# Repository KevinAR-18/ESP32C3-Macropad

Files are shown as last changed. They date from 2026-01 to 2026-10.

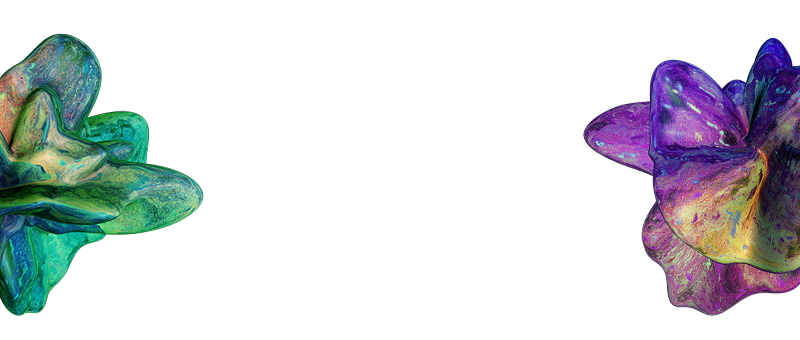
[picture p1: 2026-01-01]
images/bg3.png

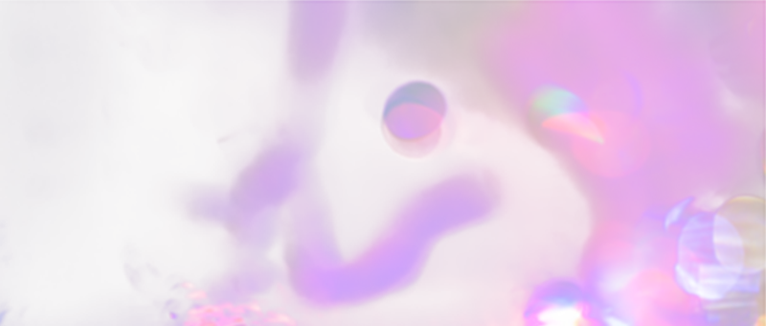
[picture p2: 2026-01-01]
images/bg.png

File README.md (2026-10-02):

# KeyBloom

KeyBloom is a Windows desktop companion for a custom ESP32-C3 macro pad. It provides a PySide6-based interface to configure multiple profiles, map each hardware button to a keyboard shortcut or application launcher, and keep the app running in the system tray while listening to serial events from the device.

## Features

- 5 configurable profiles
- 6 slots per profile
- Keyboard shortcut capture with presets
- Media key capture support, including fallback for `Fn`-based media keys
- Application launcher per slot
- ESP32 serial auto-detection with reconnect retry/backoff
- USB-priority transport with verified handshake and heartbeat
- BLE scan/connect/disconnect/forget inside KeyBloom, with saved-device reconnect
- BLE idle power reduction and encoder-1-only deep-sleep wake
- System tray mode for background runtime
- Windows startup integration with start-minimized tray behavior
- Default startup page always returns to Profile 1
- Settings stored in `%APPDATA%\KeyBloom\settings.json`
- Spotify session volume control for the second encoder
- KiCad PCB files included in the repository
- ESP32-C3 firmware source included in the repository

## Project Structure

- [main.py](./main.py): application entry point and main runtime logic
- [keybloom.ui](./keybloom.ui): Qt Designer source file
- [ui/ui_keybloom.py](./ui/ui_keybloom.py): generated Qt UI file
- [ui/preview_button.py](./ui/preview_button.py): custom keycap preview widget
- [ui/ui_functions.py](./ui/ui_functions.py): borderless window and drag helpers
- [config/settings_manager.py](./config/settings_manager.py): settings load/save and profile serialization
- [input/key_capture.py](./input/key_capture.py): shortcut capture event filter
- [input/shortcut_utils.py](./input/shortcut_utils.py): shortcut normalization helpers
- [serial_tools/port_detector.py](./serial_tools/port_detector.py): serial port auto-detection helpers
- [connection/manager.py](./connection/manager.py): background USB/BLE transport and connection policy
- [connection/dialog.py](./connection/dialog.py): connection and power settings dialog
- [utils/date_utils.py](./utils/date_utils.py): clock/date formatting helper
- [resources.qrc](./resources.qrc): Qt resource manifest
- [resources_rc.py](./resources_rc.py): generated Qt resource module
- [build.bat](./build.bat): main PyInstaller build script
- [KeyBloom.spec](./KeyBloom.spec): PyInstaller spec file
- [examplebuildbat.bat](./examplebuildbat.bat): simplified build example
- [PCB_Macropad/Macropad_PCB](./PCB_Macropad/Macropad_PCB): KiCad project for the macro pad PCB
- [ProgramESP32C3_Macropad/ProgramESP32C3_Macropad.ino](./ProgramESP32C3_Macropad/ProgramESP32C3_Macropad.ino): ESP32-C3 firmware source
- [bluetooth_test](./bluetooth_test): isolated ESP32-C3 BLE communication prototype for Windows 11

## Requirements

- Windows
- Python 3.12+ recommended
- A virtual environment in `.venv`
- ESP32-C3 macro pad firmware that sends serial messages compatible with the app

Install dependencies:

```powershell
.venv\Scripts\python.exe -m pip install -r requirements.txt
```

## Running From Source

```powershell
.venv\Scripts\python.exe main.py
```

## Runtime Behavior

- When Auto Startup is enabled, Windows launches KeyBloom with a start-minimized flag so the app goes directly to the system tray.
- When the main window is opened manually, the app always starts on Profile 1.
- Shortcut capture uses the Qt event path first and temporarily enables a global keyboard hook while recording, which improves capture for media keys such as `Media Next` and `Media Previous`.
- Serial auto-detect keeps retrying with a reconnect backoff when the ESP32-C3 disconnects or re-enumerates.

## Settings Location

At runtime, the app saves settings to:

```text
%APPDATA%\KeyBloom\settings.json
```

Legacy settings next to the executable or project folder are still readable as fallback.

## Build EXE

Install PyInstaller first:

```powershell
.venv\Scripts\python.exe -m pip install pyinstaller
```

Then run:

```powershell
build.bat
```

Expected output:

```text
dist\KeyBloom.exe
dist\icon.ico
```

`build.bat` also copies `icon.ico` into `dist\` after a successful build.

## Hardware Files

The repository also includes the hardware design files for the macro pad PCB.

- The KiCad project is located in [PCB_Macropad/Macropad_PCB](./PCB_Macropad/Macropad_PCB).
- The PCB design files are already prepared for production and intended for JLCPCB workflow.
- The project includes the schematic, PCB layout, and backup archives generated during board iteration.

## ESP32-C3 Firmware

### Dual USB/BLE setup

Upload `ProgramESP32C3_Macropad/ProgramESP32C3_Macropad.ino` with
**NimBLE-Arduino 2.x** installed. Compilation has been checked with Arduino-ESP32
**3.3.10**, target `esp32:esp32:esp32c3:CDCOnBoot=cdc` (native USB CDC enabled).
Choose the board/USB settings matching your actual hardware. Close Serial Monitor
before connecting KeyBloom. Update both desktop app and firmware together: the old
serial firmware and BLE test firmware do not implement the production handshake/control protocol.

Open **Settings → USB / Bluetooth Connection…**, or **Connection…** in the tray menu.

1. For USB, enable Auto Detect (or enter the COM port manually). KeyBloom verifies
   the device before selecting USB. An open COM port alone is not sufficient.
2. For BLE, click **Scan**, select `KeyBloom-C3`, then **Connect**. Use the KeyBloom
   dialog rather than Windows Bluetooth pairing. The device is saved only after
   the BLE service, control write, and event subscription succeed.
3. Saved devices reconnect on app startup and after an unexpected disconnection.
4. **Disconnect** keeps the device saved and disables reconnect, including after
   an app restart. **Connect** enables it again. **Forget device** removes the saved device.
5. USB takes priority. Removing USB permits BLE reconnect unless manually disconnected.
   A charging cable without an active KeyBloom data connection does not select USB.

The board needs battery/another power source to keep running when USB is removed.
The prototype BLE client must be closed before connecting the desktop app.

### Custom button and rotary actions

- On any profile page, click **Edit button & rotary actions…** or click a button
  preview and choose **Edit Action…**.
- Each profile has 12 mappings: six buttons and left/right/click for each rotary.
- Available actions: keyboard shortcut, media (play/pause, next, previous, stop),
  system audio, Spotify volume, open app/file/folder, URL, text, switch profile,
  and None. Spotify volume steps can be set from 1% to 100%.
- Text preserves whitespace and is typed into the focused application. Media
  controls use the Windows media session; they are not Spotify-specific.
- **Copy/Paste** copies one mapping. The profile selector copies all 12 mappings
  from another profile. **Export/Import profile** uses a portable JSON file.
  Imported/copied changes take effect only after **Save**; Cancel discards them.
- Mappings are saved in the application's settings and restored on restart.
  Existing button mappings and the original rotary defaults are retained.
- Firmware currently repeats held buttons; briefly press toggle actions such
  as Play/Pause and profile switching. Long/double press are not available yet.

### Power and wake-up behavior

- Default: after **60 seconds** of physical inactivity, request longer BLE connection
  intervals/slave latency and slower advertising when disconnected. The central
  (Windows) can negotiate different connection parameters.
- Stock Arduino-ESP32 3.3.10 in this environment has `CONFIG_PM_ENABLE` and
  `CONFIG_BT_CTRL_MODEM_SLEEP` disabled. This build reduces CPU speed to **80 MHz**
  while idle and restores **160 MHz** on activity/USB. It does **not** claim connected
  automatic light-sleep. Custom cores with compatible PM/modem-sleep/tickless-idle
  support can use the guarded PM configuration in the sketch.
- Default: after **600 seconds**, enter deep sleep and disconnect BLE. This also
  applies when advertising without a connected client. Active USB heartbeat prevents sleep.
- **Only clicking encoder 1 (GPIO 5) wakes from deep sleep.** Rotation and other
  buttons do not wake it. The complete wake click, including hold/repeat, is consumed;
  release it before using encoder 1 again.
- KeyBloom reconnects to a waking saved device unless Disconnect was selected.
  A sleeping board cannot be woken by the app's Connect button. Click encoder 1 first.
- USB plug-in wake depends on the board's power/reset wiring; do not assume it wakes
  an already battery-powered sleeping board. Use encoder 1 if needed.
- Change timings or disable deep sleep with **Save power settings**. Settings are saved
  in AppData and sent on connection; firmware persists changed power settings in NVS.
- Sleep status is shown when the firmware's notification reaches the app. A silent
  disconnect cannot reliably be identified as sleep. Reconnect scanning backs off to 30 seconds.

Hardware verification is still required: measure board current in active/idle/deep-sleep
states, confirm GPIO 5 remains pulled high when released, exercise wake/reconnect and
USB hot-plug, and check that LED/regulator consumption meets your battery-life needs.
Do not infer battery life from firmware sleep mode alone.

### Protocol and validation

BLE name/service/event UUID remain compatible with the prototype. Production adds
the writable control characteristic `7c3a0003-8f6e-4d4b-a8f3-6f8f9c1b0001`.

- USB: `KB HELLO <session>` → `KB READY <session>`.
- Heartbeat every second: `KB PING <session>` → `KB PONG <session>`; 3-second lease.
- Graceful release: `KB BYE <session>`.
- Power configuration: `KB POWER <0|1> <idle_seconds> <sleep_seconds>` over USB or BLE.
- Before deep sleep: BLE notification `KB SLEEP` (best effort).

Run desktop policy tests and the isolated UI smoke check:

```powershell
.venv\Scripts\python.exe -m unittest discover -s tests -v
.venv\Scripts\python.exe tests\smoke_ui.py
```

The ESP32-C3 firmware is already included in the repository:

- Firmware source: [ProgramESP32C3_Macropad/ProgramESP32C3_Macropad.ino](./ProgramESP32C3_Macropad/ProgramESP32C3_Macropad.ino)
- The desktop app expects the board firmware to send serial messages that match the event format documented below.

## Serial Event Format

The app currently reacts to messages such as:

```text
BUTTON 1 PRESSED
ENC1 RIGHT
ENC1 LEFT
ENC1 BUTTON PRESSED
ENC2 RIGHT
ENC2 LEFT
ENC2 BUTTON PRESSED
START
```

## Notes

- The UI is generated from `keybloom.ui`, but runtime optimizations are handled in Python code.
- The app is tuned to stay lighter while minimized to tray by reducing unnecessary timers, delayed widget setup, and lazy-loading heavy modules.
- `requirements.txt` is kept intentionally small to match the runtime dependencies used by the current app.

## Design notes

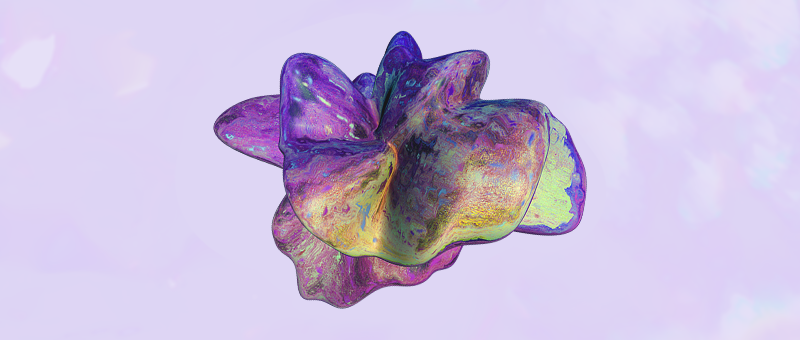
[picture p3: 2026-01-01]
images/bg2.png

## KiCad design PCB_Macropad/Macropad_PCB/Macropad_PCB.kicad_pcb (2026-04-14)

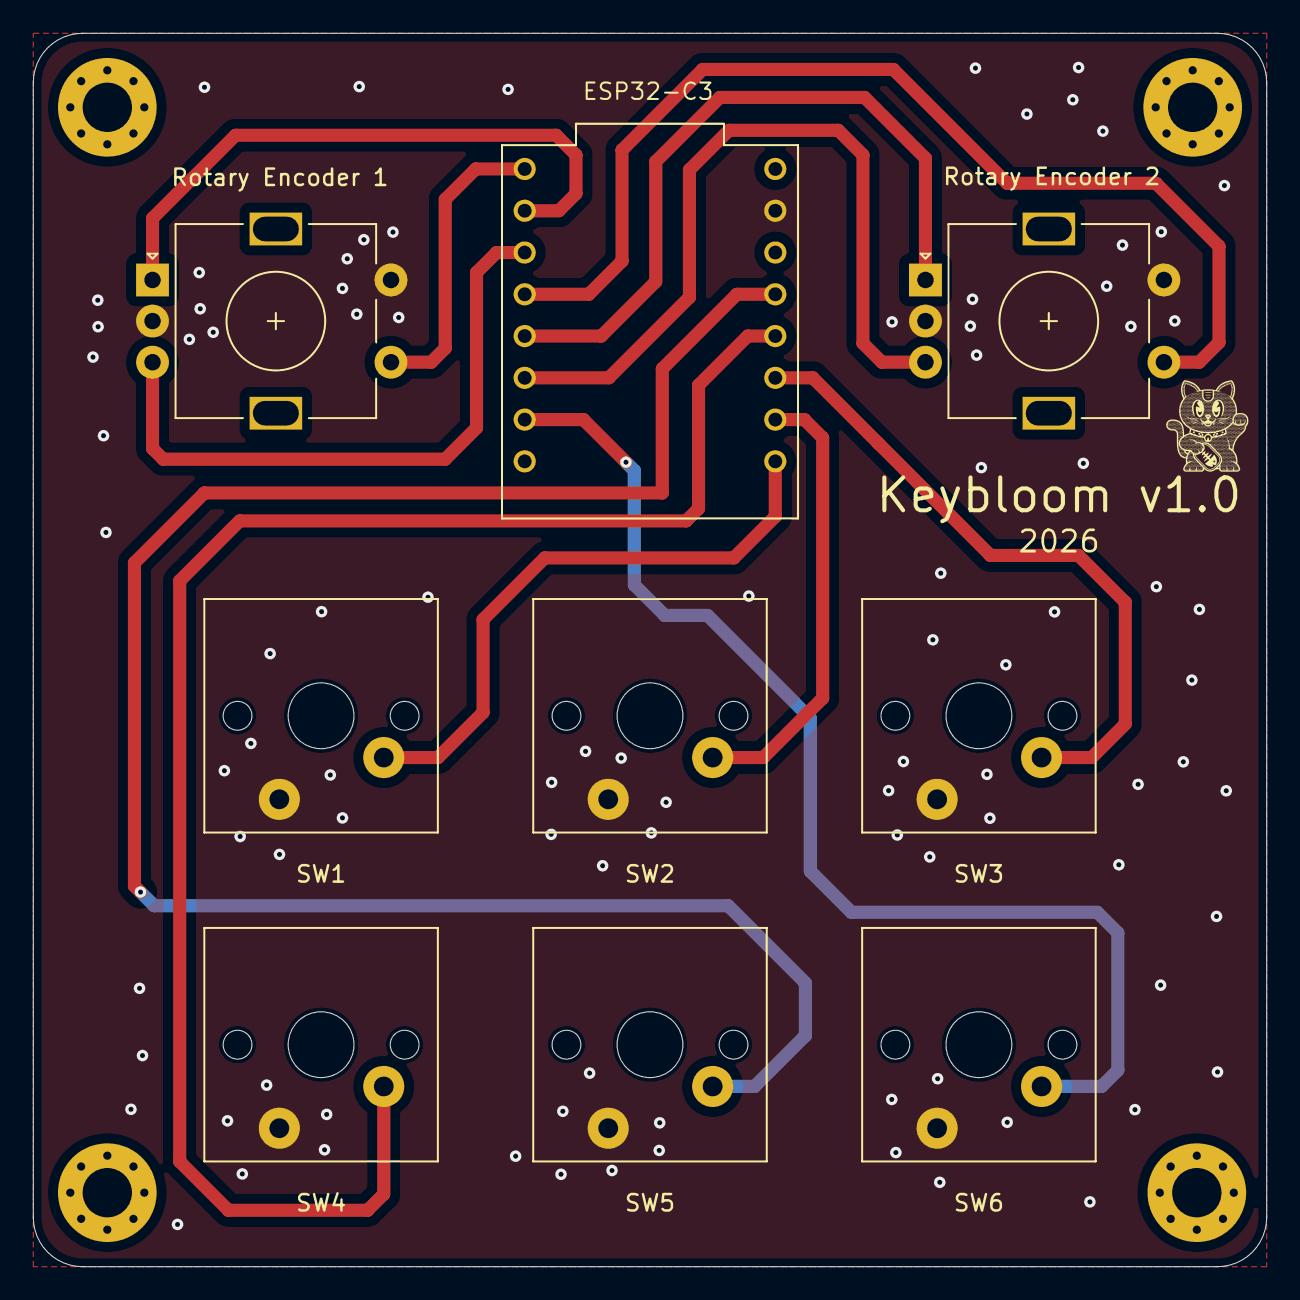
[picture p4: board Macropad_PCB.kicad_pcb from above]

Board: 2 copper layers, 75.0 x 75.0 mm, 13 parts (0 on the bottom side), 13 nets.

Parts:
ESP32-C3: ESP32-C3; MODULE_ESP32-C3_SUPERMINI_TH
H3, H4, H5, H6: MountingHole; MountingHole_3mm_Pad_Via
Rotary Encoder 1: Rotary Encoder Switch 1; RotaryEncoder_Alps_EC11E-Switch_Vertical_H20mm
Rotary Encoder 2: Rotary Encoder Switch 2; RotaryEncoder_Alps_EC11E-Switch_Vertical_H20mm
SW1: Button 1; SW_Cherry_MX_PCB_1.00u
SW2: Button 2; SW_Cherry_MX_PCB_1.00u
SW3: Button 3; SW_Cherry_MX_PCB_1.00u
SW4: Button 4; SW_Cherry_MX_PCB_1.00u
SW5: Button 5; SW_Cherry_MX_PCB_1.00u
SW6: Button 6; SW_Cherry_MX_PCB_1.00u

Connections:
D0: ESP32-C3.0 (GPIO0), SW1.1 (A)
D1: ESP32-C3.1 (GPIO1), SW2.1 (A)
D2: ESP32-C3.2 (GPIO2), SW3.1 (A)
D3: ESP32-C3.3 (GPIO3), SW4.1 (A)
D4: ESP32-C3.4 (GPIO4), SW5.1 (A)
D5: ESP32-C3.5 (GPIO5), Rotary Encoder 1.S1
D6: ESP32-C3.6 (GPIO6), Rotary Encoder 1.A
D7: ESP32-C3.7 (GPIO7), Rotary Encoder 1.B
D8: ESP32-C3.8 (GPIO8), Rotary Encoder 2.S1
D9: ESP32-C3.9 (GPIO9), Rotary Encoder 2.A
D10: ESP32-C3.10 (GPIO10), Rotary Encoder 2.B
D20: ESP32-C3.20 (GPIO20), SW6.1 (A)
GND: ESP32-C3.G (GND), Rotary Encoder 1.C, Rotary Encoder 1.S2, Rotary Encoder 2.C, Rotary Encoder 2.S2, SW1.2 (B), SW2.2 (B), SW3.2 (B), SW4.2 (B), SW5.2 (B), SW6.2 (B)

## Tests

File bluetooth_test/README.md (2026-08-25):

# KeyBloom ESP32-C3 BLE Prototype

Prototype ini menguji komunikasi BLE antara ESP32-C3 dan Windows 11 tanpa mengubah aplikasi atau firmware utama KeyBloom.

## Arsitektur

- Nama BLE: `KeyBloom-C3`
- Service UUID: `7c3a0001-8f6e-4d4b-a8f3-6f8f9c1b0001`
- Event characteristic UUID: `7c3a0002-8f6e-4d4b-a8f3-6f8f9c1b0001`
- Transport: custom BLE GATT notification
- Pairing tidak diperlukan untuk prototype ini

Format event sengaja sama dengan firmware serial utama:

```text
BUTTON 1 PRESSED
ENC1 RIGHT
ENC1 LEFT
ENC1 BUTTON PRESSED
ENC2 RIGHT
ENC2 LEFT
ENC2 BUTTON PRESSED
```

## 1. Siapkan Arduino IDE

1. Pastikan board package `esp32 by Espressif Systems` sudah terpasang.
2. Pilih board ESP32-C3 yang sesuai dengan hardware.
3. Buka `ESP32C3_BLE_Test/ESP32C3_BLE_Test.ino`.
4. Install library `NimBLE-Arduino` versi 2.x melalui Library Manager.
5. Upload firmware ke ESP32-C3.
6. Buka Serial Monitor dengan baud `115200`.

Output awal yang diharapkan:

```text
[BLE] Advertising as KeyBloom-C3
START
```

## 2. Siapkan Python

Dari root repository:

```powershell
python -m venv bluetooth_test\.venv
bluetooth_test\.venv\Scripts\python.exe -m pip install -r bluetooth_test\requirements.txt
```

## 3. Scan Perangkat

Pastikan Bluetooth Windows 11 aktif, lalu jalankan:

```powershell
bluetooth_test\.venv\Scripts\python.exe bluetooth_test\bluetooth_test.py --scan-only
```

Cari perangkat bernama `KeyBloom-C3` atau baris yang memiliki marker `<KeyBloom>`.

## 4. Connect dan Dengarkan Event

```powershell
bluetooth_test\.venv\Scripts\python.exe bluetooth_test\bluetooth_test.py
```

Tekan tombol dan putar encoder. Contoh output:

```text
[BLE] Connected: True
[14:20:30.804] [EVENT] START
[BLE] Listening for events. Press Ctrl+C to stop.
[14:20:31.125] [EVENT] BUTTON 1 PRESSED
[14:20:33.421] [EVENT] ENC1 RIGHT
```

Klien otomatis melakukan scan dan reconnect ketika ESP32 dimatikan atau koneksi terputus.

Jika pencarian berdasarkan nama gagal tetapi alamat terlihat saat scan, gunakan:

```powershell
bluetooth_test\.venv\Scripts\python.exe bluetooth_test\bluetooth_test.py --address "ALAMAT_DARI_HASIL_SCAN"
```

Pada Windows, address dari Bleak dapat berupa UUID dan bukan MAC address. Gunakan nilai persis seperti hasil scan.

## Checklist Pengujian

- ESP32 muncul sebagai `KeyBloom-C3`.
- Python dapat connect tanpa pairing manual.
- Semua enam tombol menghasilkan event yang benar.
- Kedua encoder menghasilkan arah dan event tombol yang benar.
- Tidak ada event ganda untuk satu detent encoder.
- Python mendeteksi disconnect ketika ESP32 dimatikan.
- Python reconnect setelah ESP32 dinyalakan kembali.
- Koneksi tetap stabil setidaknya 30 menit.

## Catatan

- ESP32-C3 mendukung BLE, bukan Bluetooth Classic SPP.
- Firmware ini tetap mencetak semua event ke serial untuk membantu debugging.
- Jangan mengganti firmware utama sebelum prototype ini lolos pengujian.

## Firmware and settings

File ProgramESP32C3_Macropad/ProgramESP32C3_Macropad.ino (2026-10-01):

#include <NimBLEDevice.h>
#include <Preferences.h>
#include <esp_sleep.h>
#include <esp_pm.h>
#include <driver/gpio.h>

// ESP32-C3 / NimBLE-Arduino 2.x. GPIO 5 is the ONLY deep-sleep wake button.
const uint8_t buttonPins[] = {0, 1, 2, 3, 4, 20, 5, 8};
const uint8_t encA[] = {6, 9};
const uint8_t encB[] = {7, 10};
const char *SERVICE_UUID = "7c3a0001-8f6e-4d4b-a8f3-6f8f9c1b0001";
const char *EVENT_UUID = "7c3a0002-8f6e-4d4b-a8f3-6f8f9c1b0001";
const char *CONTROL_UUID = "7c3a0003-8f6e-4d4b-a8f3-6f8f9c1b0001";
constexpr uint32_t DEBOUNCE_MS = 50, REPEAT_DELAY = 400, REPEAT_RATE = 80;
constexpr uint32_t USB_TIMEOUT = 3000;

struct Button {
  bool raw = HIGH, stable = HIGH;
  uint32_t changed = 0, pressed = 0, repeated = 0;
};
Button buttons[8];
int lastEncoderA[2];
bool suppressWakeClick = false;
uint32_t lastActivity = 0, lastHeartbeat = 0;
bool usbActive = false, idleMode = false, sleepEnabled = true;
uint32_t idleMs = 60000, sleepMs = 600000;
String serialLine, usbSession;
Preferences preferences;
NimBLEServer *bleServer = nullptr;
NimBLECharacteristic *events = nullptr;
volatile bool bleConnected = false;
volatile bool restartAdvertising = false, updateParams = false;
volatile uint16_t connectionHandle = BLE_HS_CONN_HANDLE_NONE;

// BLE callbacks run on another task. Transfer configuration through a bounded queue.
struct ControlMessage { char text[80]; };
QueueHandle_t controls;

class ServerCallbacks : public NimBLEServerCallbacks {
  void onConnect(NimBLEServer *, NimBLEConnInfo &info) override {
    connectionHandle = info.getConnHandle();
    bleConnected = true;
    updateParams = true;
  }
  void onDisconnect(NimBLEServer *, NimBLEConnInfo &, int) override {
    bleConnected = false;
    connectionHandle = BLE_HS_CONN_HANDLE_NONE;
    restartAdvertising = true;
  }
};

class ControlCallbacks : public NimBLECharacteristicCallbacks {
  void onWrite(NimBLECharacteristic *characteristic, NimBLEConnInfo &) override {
    auto value = characteristic->getValue();
    if (value.size() >= sizeof(ControlMessage::text)) return;
    ControlMessage message = {};
    memcpy(message.text, value.c_str(), value.size());
    xQueueSend(controls, &message, 0);
  }
};

void sendEvent(const String &text) {
  if (usbActive) {
    Serial.println(text);
  } else if (bleConnected) {
    events->setValue(text.c_str());
    events->notify();
  }
}

void setPowerConfig(const String &command) {
  unsigned int enabled, idleSeconds, sleepSeconds;
  char extra;
  if (sscanf(command.c_str(), "KB POWER %u %u %u %c", &enabled, &idleSeconds,
             &sleepSeconds, &extra) != 3) return;
  if (enabled > 1 || idleSeconds < 10 || idleSeconds > 3600 ||
      sleepSeconds <= idleSeconds || sleepSeconds > 86400) return;
  bool changed = sleepEnabled != bool(enabled) || idleMs != idleSeconds * 1000UL ||
                 sleepMs != sleepSeconds * 1000UL;
  sleepEnabled = enabled;
  idleMs = idleSeconds * 1000UL;
  sleepMs = sleepSeconds * 1000UL;
  if (changed) {
    preferences.putBool("enabled", sleepEnabled);
    preferences.putUInt("idle", idleMs);
    preferences.putUInt("sleep", sleepMs);
  }
}

void handleSerial() {
  // Limit work per pass so malformed traffic cannot starve physical input.
  for (int i = 0; i < 128 && Serial.available(); ++i) {
    char c = Serial.read();
    if (c == '\n') {
      serialLine.trim();
      if (serialLine.startsWith("KB HELLO ") && serialLine.length() <= 50) {
        usbSession = serialLine.substring(9);
        if (!usbSession.isEmpty()) {
          usbActive = true;
          lastHeartbeat = millis();
          Serial.println("KB READY " + usbSession);
        }
      } else if (usbActive && serialLine == "KB PING " + usbSession) {
        lastHeartbeat = millis();
        Serial.println("KB PONG " + usbSession);
      } else if (usbActive && serialLine == "KB BYE " + usbSession) {
        usbActive = false;
        lastActivity = millis();
      } else if (usbActive && serialLine.startsWith("KB POWER ")) {
        setPowerConfig(serialLine);
      }
      serialLine = "";
    } else if (c != '\r') {
      if (serialLine.length() < 79) serialLine += c;
      else serialLine = "";
    }
  }
  if (usbActive && millis() - lastHeartbeat >= USB_TIMEOUT) {
    usbActive = false;
    // Allow a full reconnect window after cable removal.
    lastActivity = millis();
  }
}

void setupBle() {
  NimBLEDevice::init("KeyBloom-C3");
  bleServer = NimBLEDevice::createServer();
  bleServer->setCallbacks(new ServerCallbacks());
  auto service = bleServer->createService(SERVICE_UUID);
  events = service->createCharacteristic(EVENT_UUID, NIMBLE_PROPERTY::READ | NIMBLE_PROPERTY::NOTIFY);
  events->setValue("START");
  auto control = service->createCharacteristic(CONTROL_UUID, NIMBLE_PROPERTY::WRITE);
  control->setCallbacks(new ControlCallbacks());
  service->start();
  auto advertising = NimBLEDevice::getAdvertising();
  advertising->addServiceUUID(SERVICE_UUID);
  advertising->setName("KeyBloom-C3");
  advertising->enableScanResponse(true);
  advertising->setMinInterval(160); // 100–200 ms during discovery
  advertising->setMaxInterval(320);
  advertising->start();
}

void emitButton(int index) {
  if (index < 6) sendEvent("BUTTON " + String(index + 1) + " PRESSED");
  else sendEvent("ENC" + String(index - 5) + " BUTTON PRESSED");
}

void handleInputs() {
  uint32_t now = millis();
  for (int i = 0; i < 8; ++i) {
    bool raw = digitalRead(buttonPins[i]);
    auto &b = buttons[i];
    if (raw != b.raw) {
      b.raw = raw;
      b.changed = now;
      lastActivity = now;
    }
    // Consume the entire wake click, including contact bounce and hold repeats.
    if (i == 6 && suppressWakeClick) {
      b.stable = raw;
      if (raw == HIGH && now - b.changed >= DEBOUNCE_MS) suppressWakeClick = false;
      continue;
    }
    if (raw != b.stable && now - b.changed >= DEBOUNCE_MS) {
      b.stable = raw;
      if (raw == LOW) {
        b.pressed = b.repeated = now;
        emitButton(i);
      }
    } else if (b.stable == LOW && raw == LOW && now - b.pressed >= REPEAT_DELAY &&
               now - b.repeated >= REPEAT_RATE) {
      emitButton(i);
      b.repeated = now;
    }
    if (raw == LOW) lastActivity = now;
  }
  for (int i = 0; i < 2; ++i) {
    int a = digitalRead(encA[i]);
    if (a != lastEncoderA[i]) {
      lastActivity = now;
      sendEvent("ENC" + String(i + 1) + (digitalRead(encB[i]) != a ? " LEFT" : " RIGHT"));
      lastEncoderA[i] = a;
    }
  }
}

void handlePower() {
  uint32_t elapsed = millis() - lastActivity;
  bool idle = !usbActive && elapsed >= idleMs;
  if (idle != idleMode || updateParams) {
    updateParams = false;
    idleMode = idle;
#if !defined(CONFIG_PM_ENABLE) || !CONFIG_PM_ENABLE
    // Stock Arduino builds usually disable dynamic power management. 80 MHz
    // keeps the BLE controller supported while reducing idle CPU consumption.
    setCpuFrequencyMhz(idle ? 80 : 160);
#endif
    if (bleConnected) {
      // Units: interval 1.25 ms, timeout 10 ms. Central may negotiate differently.
      bleServer->updateConnParams(connectionHandle, idle ? 80 : 12,
                                 idle ? 160 : 24, idle ? 4 : 0, 600);
    }
    auto advertising = NimBLEDevice::getAdvertising();
    if (!bleConnected) advertising->stop();
    advertising->setMinInterval(idle ? 1600 : 160);
    advertising->setMaxInterval(idle ? 2400 : 320);
    if (!bleConnected) advertising->start();
  }
  if (restartAdvertising) {
    restartAdvertising = false;
    NimBLEDevice::startAdvertising();
  }
  if (!usbActive && sleepEnabled && elapsed >= sleepMs) {
    for (auto pin : buttonPins) if (digitalRead(pin) == LOW) return;
    sendEvent("KB SLEEP");
    delay(100); // Allow the sleep notification to leave before shutting down BLE.
    NimBLEDevice::deinit(true);
    // C3 deep-sleep GPIO wake supports GPIO 0–5 only; encoder 1 switch is GPIO 5.
    esp_deep_sleep_enable_gpio_wakeup(1ULL << 5, ESP_GPIO_WAKEUP_GPIO_LOW);
    gpio_pullup_en(GPIO_NUM_5);
    gpio_pulldown_dis(GPIO_NUM_5);
    esp_deep_sleep_start();
  }
}

void setup() {
  Serial.begin(115200);
  serialLine.reserve(80);
  controls = xQueueCreate(4, sizeof(ControlMessage));
  preferences.begin("keybloom", false);
  sleepEnabled = preferences.getBool("enabled", true);
  idleMs = preferences.getUInt("idle", 60000);
  sleepMs = preferences.getUInt("sleep", 600000);
  if (idleMs < 10000 || idleMs > 3600000 || sleepMs <= idleMs || sleepMs > 86400000) {
    idleMs = 60000;
    sleepMs = 600000;
  }
  for (auto pin : buttonPins) pinMode(pin, INPUT_PULLUP);
  for (int i = 0; i < 2; ++i) {
    pinMode(encA[i], INPUT_PULLUP);
    pinMode(encB[i], INPUT_PULLUP);
    lastEncoderA[i] = digitalRead(encA[i]);
  }
  suppressWakeClick = esp_sleep_get_wakeup_cause() == ESP_SLEEP_WAKEUP_GPIO;
  // PM depends on the Arduino core build. Never force manual light-sleep with BLE.
#if defined(CONFIG_PM_ENABLE) && CONFIG_PM_ENABLE
  esp_pm_config_t pm = {};
  pm.max_freq_mhz = 160;
  pm.min_freq_mhz = 40;
#if defined(CONFIG_FREERTOS_USE_TICKLESS_IDLE) && CONFIG_FREERTOS_USE_TICKLESS_IDLE && defined(CONFIG_BT_CTRL_MODEM_SLEEP) && CONFIG_BT_CTRL_MODEM_SLEEP
  pm.light_sleep_enable = true;
#endif
  esp_pm_configure(&pm);
#endif
  setupBle();
  lastActivity = millis();
}

void loop() {
  handleSerial();
  ControlMessage message;
  if (xQueueReceive(controls, &message, 0) == pdTRUE) setPowerConfig(String(message.text));
  handleInputs();
  handlePower();
  // Yield to the RTOS/BLE tasks without slowing encoder polling in idle mode.
  delay(1);
}

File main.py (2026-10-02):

import os
import re
import subprocess
import sys
from importlib import import_module
from functools import partial
from pathlib import Path

from PySide6.QtCore import QEvent, QObject, Qt, QTimer, Signal, QUrl
from PySide6.QtGui import QAction, QCursor, QFontMetrics, QIcon, QDesktopServices
from PySide6.QtWidgets import (
    QApplication,
    QFileDialog,
    QFrame,
    QMainWindow,
    QMenu,
    QDialog,
    QComboBox,
    QPushButton,
    QSystemTrayIcon,
    QVBoxLayout,
    QWidget,
)
from connection.manager import ConnectionManager
from connection.dialog import ConnectionDialog
from input.actions import default_rotary, normalize_action, ROTARY_EVENTS, ACTION_TYPES
from ui.action_editor import ActionEditor

from utils.date_utils import Date
from input.key_capture import KeyCaptureFilter
from input.shortcut_utils import (
    format_shortcut_display,
    global_event_to_shortcut_text,
    normalize_shortcut,
)
from config.settings_manager import (
    APPLICATION_MODE,
    SHORTCUT_MODE,
    apply_profile_mappings,
    apply_profile_titles,
    collect_profile_mappings,
    collect_profile_names,
    load_settings,
    save_settings,
    set_autostart,
    settings_path,
)
from ui.ui_functions import UIFunctions
from ui.ui_keybloom import Ui_MainWindow
from ui.preview_button import APP_MODE, KEYBOARD_MODE, UNSET_MODE, TransparentKeycapPreview

APP_NAME = "KeyBloom"
APP_VERSION = "1.1.0"
APP_ICON_FILE = "icon.ico"
START_MINIMIZED_ARG = "--start-minimized"
PROFILE_IDS = tuple(str(index) for index in range(1, 6))
PROFILE_LINE_COUNT = 6
SETTINGS_SAVE_DEBOUNCE_MS = 250
SPOTIFY_MODE_SESSION = "session"
SPOTIFY_WEB_STEP_PERCENT = 3

PROFILE_INPUT_STYLE = (
    "\nQLineEdit:hover { border: 2px solid #6f5fa8; background-color: rgba(255, 255, 255, 1); }"
    "\nQLineEdit:focus { border: 2px solid #584c90; background-color: rgba(255, 255, 255, 1); }"
)
PREVIEW_TOOLTIP = {
    SHORTCUT_MODE: "Klik kotak atas lalu pilih Shortcut Keyboard untuk merekam 5 detik.",
    APPLICATION_MODE: "Klik preview untuk pilih atau ganti aplikasi.",
}
CAPTURE_WINDOW_MS = 5000
ACTION_BUTTON_STYLE = """
    QPushButton {
        background-color: #65518F;
        color: #FFFFFF;
        border: 2px solid #554278;
        border-radius: 8px;
        font: bold 10pt "Segoe UI";
        padding: 6px 14px;
    }
    QPushButton:hover { background-color: #7660A3; border-color: #65518F; }
    QPushButton:pressed { background-color: #4F3D73; border-color: #423260; }
    QPushButton:focus { border-color: #D9C9FF; }
    QPushButton:disabled { background-color: #DDD6E8; color: #62596F; border-color: #BEB3CE; }
"""
SHORTCUT_PRESETS = [
    ("Alt+Tab", "Alt+Tab"),
    ("Win+Left", "Win+Left"),
    ("Win+Right", "Win+Right"),
    ("Win+Up", "Win+Up"),
    ("Win+Down", "Win+Down"),
    ("Ctrl+Win+Left", "Ctrl+Win+Left"),
    ("Ctrl+Win+Right", "Ctrl+Win+Right"),
]


def app_icon():
    if getattr(sys, "frozen", False) and hasattr(sys, "_MEIPASS"):
        icon_path = Path(sys._MEIPASS) / APP_ICON_FILE
    else:
        icon_path = Path(__file__).with_name(APP_ICON_FILE)
    if icon_path.is_file():
        return QIcon(str(icon_path))
    return QIcon(":/icon/images/icon_minimize.png")


class _PreviewClickFilter(QObject):
    def __init__(self, callback, parent=None):
        super().__init__(parent)
        self._callback = callback

    def eventFilter(self, obj, event):
        if isinstance(obj, QWidget) and event.type() == QEvent.MouseButtonRelease:
            if event.button() == Qt.LeftButton:
                self._callback(obj)
                return True
        return super().eventFilter(obj, event)


class MainWindow(QMainWindow):
    global_shortcut_captured = Signal(str)

    def __init__(self, start_minimized: bool = False):
        super().__init__()
        self._start_minimized = start_minimized
        if self._start_minimized:
            # Prevent a visible startup flash when Windows launches the app
            # from autostart.
            self.setAttribute(Qt.WA_DontShowOnScreen, True)
        self.ui = Ui_MainWindow()
        self.ui.setupUi(self)
        # Override designer size constraints together so the inner frames grow too.
        for widget in (self, self.ui.styleSheet, self.ui.bgApp):
            widget.setFixedSize(800, 420)
        self.setWindowTitle(APP_NAME)
        self.setWindowIcon(app_icon())
        self.ui.version.setText(f"v{APP_VERSION}")

        self._loading_settings = False
        self._settings_initialized = False
        self._date_helper = Date()
        self._key_filter = KeyCaptureFilter(self)
        self._preview_filter = _PreviewClickFilter(self._on_preview_clicked, self)
        self._active_capture_slot = None
        self._shortcut_capture_timer = QTimer(self)
        self._shortcut_capture_timer.setSingleShot(True)
        self._shortcut_capture_timer.timeout.connect(self._stop_shortcut_capture)
        self._settings_save_timer = QTimer(self)
        self._settings_save_timer.setSingleShot(True)
        self._settings_save_timer.timeout.connect(self._save_settings)
        self._connection_settings = {}
        self._current_profile_id = "1"
        self._rotary_mappings = {pid: default_rotary() for pid in PROFILE_IDS}
        self._spotify_volume = None
        self._keyboard = None
        self._keyboard_capture_hook = None
        self._pycaw_interfaces = None
        self._psutil = None
        self.global_shortcut_captured.connect(self._apply_global_shortcut_capture)

        self._profile_name_inputs = self._build_profile_name_inputs()
        self._profile_title_labels = self._build_profile_title_labels()
        self._profile_pages = self._build_profile_pages()
        self._profile_buttons = self._build_profile_buttons()
        self._save_buttons = self._build_save_buttons()
        self._profile_slots = self._build_profile_slots()
        for pid in PROFILE_IDS:
            button = QPushButton("Edit button & rotary actions…", self._profile_pages[pid])
            button.setObjectName(f"editActionsButton{pid}")
            button.setCursor(Qt.PointingHandCursor)
            button.setStyleSheet(ACTION_BUTTON_STYLE)
            button.setToolTip("Customize all six buttons and both rotary encoders for this profile")
            button.clicked.connect(lambda checked=False, profile=pid: self._edit_actions(profile))
            self._profile_pages[pid].layout().addWidget(button, 0, Qt.AlignHCenter)
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

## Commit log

2026-02-07 update latest
    [Macropad_PCB.kicad_sch]
2026-04-14 Add netlist file for PCB Macropad with detailed component connections
    [Keybloom_v1.0_bom.csv, Keybloom_v1.0_designators.csv, Keybloom_v1.0_positions.csv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]
2026-04-15 Remove obsolete files for Keybloom v1.0 production, including design files, BOM, and netlist.
    [Keybloom_v1.0_bom.csv, Keybloom_v1.0_designators.csv, Keybloom_v1.0_positions.csv]
2026-04-19 Add Coba Button Preview and Transparent Keycap Preview
    - Implemented DemoWindow class in cobabutton.py for displaying keycap previews.
    - Created TransparentKeycapPreview class in preview_button.py for rendering individual keycap previews with animation effects.
    - Introduced modes for keycap previews: unset, application, and keyboard.
    - Added buttons to set the mode of all previews in the DemoWindow.
    - Enhanced visual styles for the UI components with custom stylesheets.
2026-04-20 Add lock file for Macropad PCB design
2026-04-20 feat: Enhance Spotify integration and serial communication
    - Added Spotify mode selection and API credentials input fields in the UI.
    - Updated settings management to include serial port configuration and Spotify settings.
    - Implemented serial communication for button presses and rotary encoder events.
    - Refactored settings loading and saving logic to accommodate new configurations.
    - Improved button handling and added functionality for Spotify volume control.
    - Updated .gitignore to exclude sensitive files and unnecessary cache files.
    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
2026-04-22 Refactor MainWindow for lazy loading and improved memory management
    - Introduced lazy loading for keyboard, psutil, and pycaw modules to reduce startup overhead.
    - Increased SERIAL_POLL_MS from 25 to 40 for better serial communication stability.
    - Added a buffer limit for serial data to prevent memory overflow.
    - Removed unused Spotify UI elements to optimize memory usage.
    - Updated settings management to save in AppData for better permissions handling.
    - Enhanced error handling for module imports and serial communication.
    - Improved profile slot initialization to only set up widgets when needed.
    - Updated UI elements and styles for better user experience.
    - Added README.md for project docum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
    [ESP32-C3_SUPERMINI_TH.step]
2026-05-10 Add utility module and date handling functionality
    - Created a new utility module `__init__.py` for KeyBloom helpers.
    - Implemented `date_utils.py` with a `Date` class to update QLabel with current time and date.
2026-07-18 feat: Enhance build script and settings management with versioning and shortcut normalization
    [main.py]
2026-08-25 feat: Add ESP32-C3 BLE GATT prototype firmware using NimBLE
2026-08-25 docs: Add BLE prototype testing guide and project structure link
2026-10-01 feat: add BLE and power management firmware
2026-10-02 feat: integrate per-profile button and rotary actions
2026-10-02 docs: document custom button and rotary mappings
2026-10-13 feat: refine rotary action editing with improved button text and functionality
